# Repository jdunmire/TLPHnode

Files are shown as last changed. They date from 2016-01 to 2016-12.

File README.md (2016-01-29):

TLPHnode
=========
This is a [KiCad](http://kicad-pcb.org/) project for an ESP8266 based
temperature, light, pressure, and humidity node.

Additional information about this node can be found at the 
[Sensor Nodes](http://sensornodeinfo.rockingdlabs.com) website.

Copyright Jerry Dunmire 2016.

This documentation describes Open Hardware and is licensed under the
CERN OHL v. 1.2.

You may redistribute and modify this documentation under the terms of
the CERN OHL v.1.2. (LICENSE.txt). This documentation is distributed
WITHOUT ANY EXPRESS OR IMPLIED WARRANTY, INCLUDING OF MERCHANTABILITY,
SATISFACTORY QUALITY AND FITNESS FOR A PARTICULAR PURPOSE. Please see
the CERN OHL v.1.2 for applicable conditions

Guidelines on how to apply the CERN OHL v1.2 are in the
cern_ohl_v_1_2_howto.pdf file.

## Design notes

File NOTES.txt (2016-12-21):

###Fri 25 Nov 2016 04:06:11 PM PST
    - For a rechargable option:
       - LiFePO4 18350 sized battery
       - bq25070 ($2.46) or ADP5063 ($3.43) charger
       - MIC5528 ($0.19) or AP7365 ($0.40) 3.3v linear regulator
       - Use battery holder with lugs or wires
       - The chargers can yield a battery output voltage 4.9v, or
         possibly higher. So a regulator is needed.
       - Watch for quiesent currents (which are similar to the ESP8266!)

    - The TLPHnode board should be minimized to reduce cost. Use wires
      to the power source which could be 2 Alkaline AA, or a single
      LiFePO4.

    - The charging circuit could be on the PCB but not populated.

    - The linear regulator could be used to provide a USB powered
      option with the AA batteries as backup.

###Sun 27 Nov 2016 11:38:00 AM PST
    - Use a 6 pin connector and ribbon so that the prgm switch can be
      moved to the 'programming' board.
    - Use a LDO linear regulator on the sensor board to protect from
      over voltage of LiFePO4, or even LiPoly, batteries.
    - Put the battery charger IC on the programming board or a separate
      battery supply board.
    - The 'programming' board can be fab as part of the sensor board.
      Use holes or a cutout to make it easier to separate the board.

###Mon 05 Dec 2016 11:53:34 AM PST
    - ST Micro is not forthcoming on the adjustable regulator. So try
      the fixed, even though it is small. Consider laying out a foot
      print for an alternative regulator in addition to the ST Micro.
      I'm not ready to give up on the ST Micro regulator because it has
      such a log quesent current.
      
    TODO:
      - fix alignment between ESP-12 model and ESP-12E footprint - DONE
      - Change pin numbering on ESP-12E footprint to match ESP-12 - DONE
      - change to ESP-12
      - Re-organize footprints - DONE
      - Add 3d models
            - Regulator - flipchip-4
            - RPC connector
            - Switch
            
      - Settle on FPC connector (datasheet is wrong)
      - Update BOM at Digikey
      - 

###Tue 06 Dec 2016 10:00:03 AM PST
    - In order to use a 4 layer board for less than the cost of the last
      board, the area must be less than 1.42 square inches.
    - Keep in mind that a 2 layer board is still 1/2 of that price, but
      the there are other advantages including smaller traces, drills
      and annual rings.

    LIBRARIES
    ---------
    KiCAD has three collections that could be described as libraries:
        - schematic symbols (typically in a library/ directory)
        - 3d models (typically in a modules/packages3d/ directory)
        - footprints
          These are the tough ones to keep straight.
            - The new 'footprint collection structure' is a directory of
              directories.
            - Each sub-directory ends in .pretty.
            - Actual footprints are in individual files beneath the
              *.pretty/ directories.
            - Each *.pretty directory must be added as a separate path.
            - Each *.pretty directory is an individual git repository.
            - There is not clear parent directory name, though in
              ~/kicad/README.md I proposed putting them in the modules/
              directory with the 3d-models

###Thu 08 Dec 2016 09:47:13 PM PST
    - The LPS25HB (pressure sensor) can not be used on an OSH 2 layer
      board because there is not enough clearance between the corner
      pins. The error is 0.3 mils.
    - Set the default design rules as close to the 2 layer as possible,
      while allowing the LPS25HB to be used.

###Mon 12 Dec 2016 02:35:20 PM PST
    - Changed to 6-pin FPC connnector and 2-pin through-hole connector
      for power.

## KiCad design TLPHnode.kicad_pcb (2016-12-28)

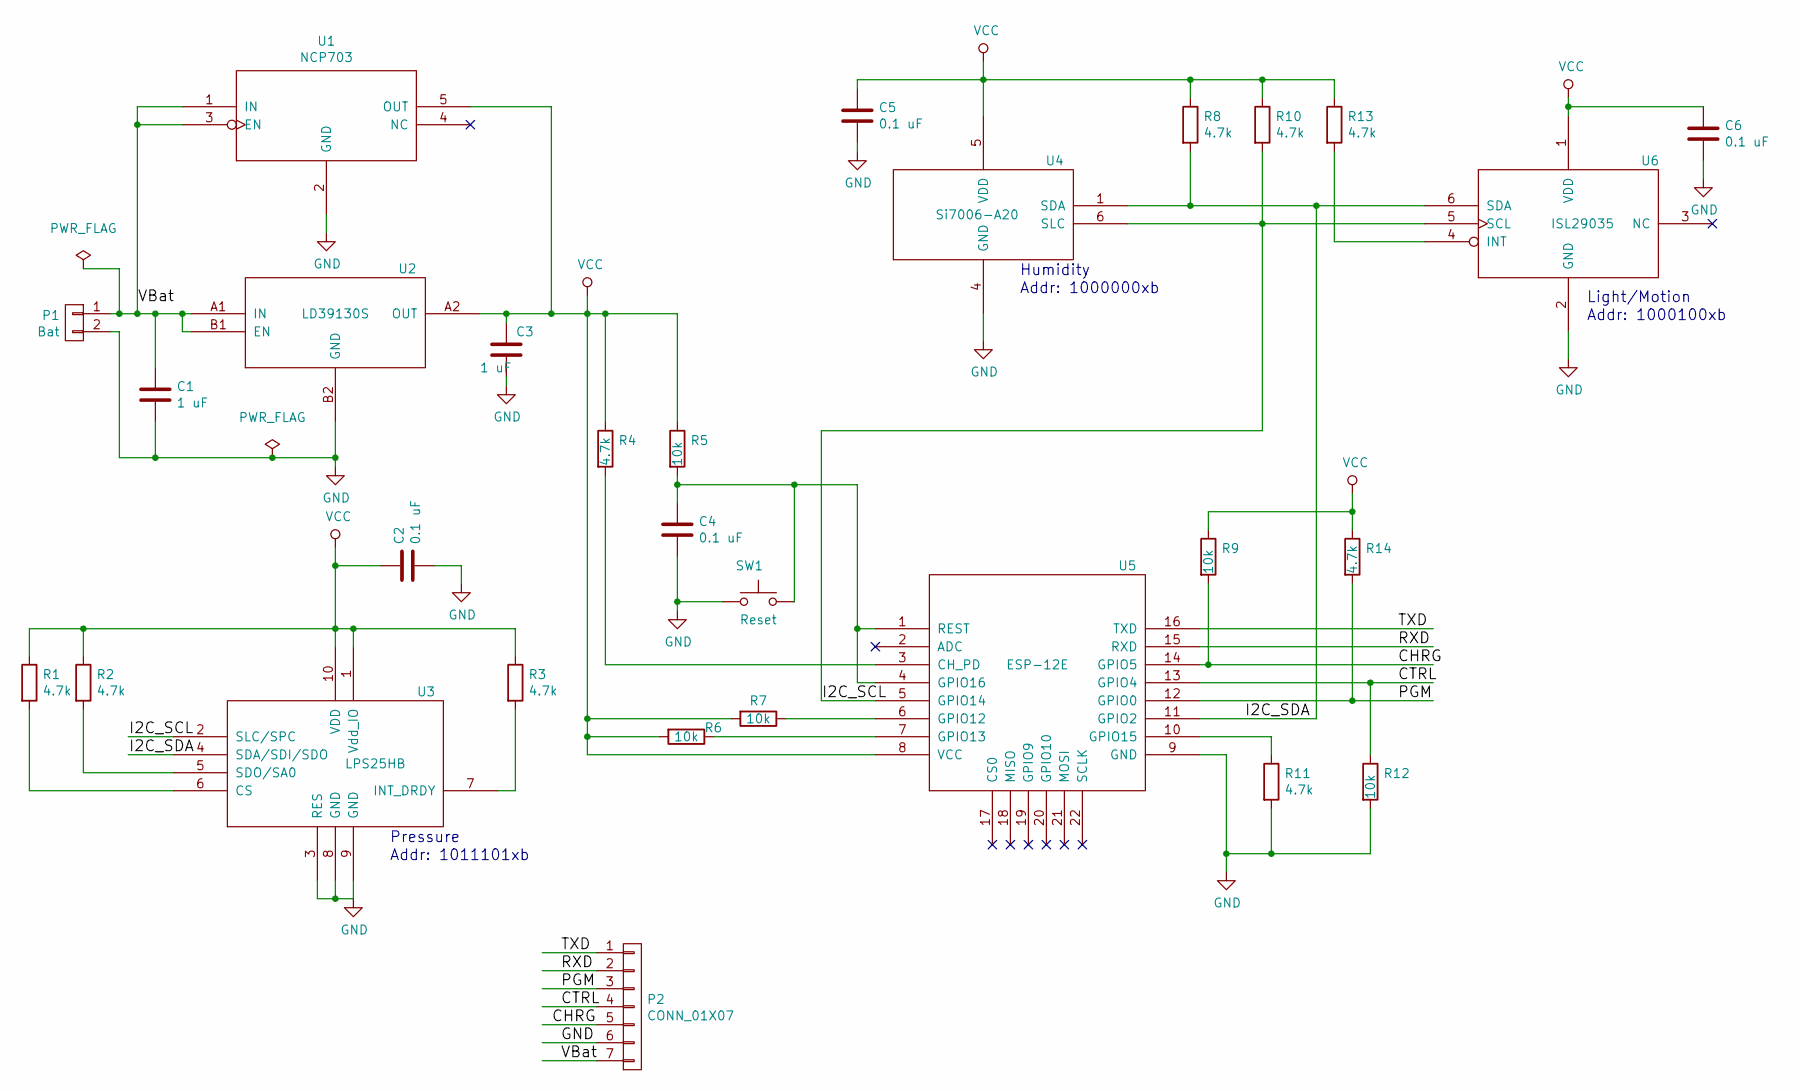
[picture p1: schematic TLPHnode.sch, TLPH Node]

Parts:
C1, C3: 1 uF; C_0603
C2, C4, C5, C6: 0.1 uF; C_0603
P1: Bat; Pin_Header_Straight_1x02
P2: CONN_01X07; FPC_conn-7_8x4.9mm_Pitch0.5mm
R1, R2, R3, R4, R8, R10, R11, R13, R14: 4.7k; R_0603
R5, R6, R7, R9, R12: 10k; R_0603
SW1: Reset; ESwitch-SMD-4
U1: NCP703; NCP703-TSOP-5
U2: LD39130S; LD39130S-FlipChip-4
U3: LPS25HB; LPS25HB-HLGA-10L-2.5x2.5mm
U4: Si7006-A20; Si7006_A20-DFN-6
U5: ESP-12E
U6: ISL29035; ISL29035-DFN-6-1.5x1.6mm_Pitch0.5mm

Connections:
/CHRG: P2.5, R9.2, U5.14 (GPIO5)
/CTRL: P2.4, R12.1, U5.13 (GPIO4)
/I2C_SCL: R10.2, U3.2 (SLC/SPC), U4.6 (SLC), U5.5 (GPIO14), U6.5 (SCL)
/I2C_SDA: R8.2, U3.4 (SDA/SDI/SDO), U4.1 (SDA), U5.11 (GPIO2), U6.6 (SDA)
/PGM: P2.3, R14.2, U5.12 (GPIO0)
/RXD: P2.2, U5.15 (RXD)
/TXD: P2.1, U5.16 (TXD)
/VBat: C1.1, P1.1, P2.7, U1.1 (IN), U1.3 (EN), U2.A1 (IN), U2.B1 (EN)
GND: C1.2, C2.2, C3.2, C4.2, C5.2, C6.2, P1.2, P2.6, R11.2, R12.2, SW1.1, U1.2 (GND), U2.B2 (GND), U3.3 (RES), U3.8 (GND), U3.9 (GND), U4.4 (GND), U5.9 (GND), U6.2 (GND)
unnamed: C4.1, R5.2, SW1.2, U5.1 (REST), U5.4 (GPIO16)
unnamed: R1.2, U3.6 (CS)
unnamed: R2.2, U3.5 (SDO/SA0)
unnamed: R3.2, U3.7 (INT_DRDY)
unnamed: R4.2, U5.3 (CH_PD)
unnamed: R6.1, U5.7 (GPIO13)
unnamed: R7.1, U5.6 (GPIO12)
unnamed: R11.1, U5.10 (GPIO15)
unnamed: R13.2, U6.4 (INT)
VCC: C2.1, C3.1, C5.1, C6.1, R1.1, R2.1, R3.1, R4.1, R5.1, R6.2, R7.2, R8.1, R9.1, R10.1, R13.1, R14.1, U1.5 (OUT), U2.A2 (OUT), U3.1 (Vdd_IO), U3.10 (VDD), U4.5 (VDD), U5.8 (VCC), U6.1 (VDD)

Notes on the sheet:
Pressure
Light/Motion
Humidity
Addr: 1011101xb
Addr: 1000000xb
Addr: 1000100xb

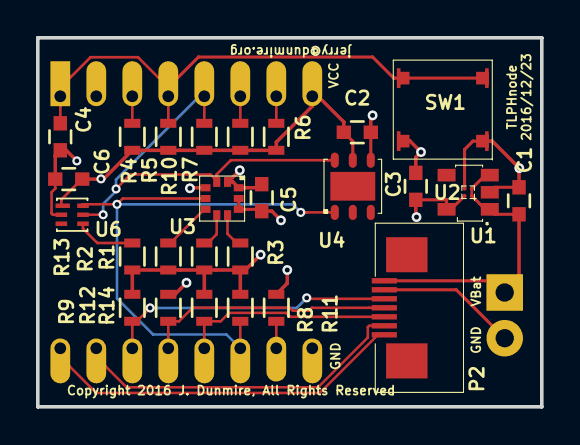
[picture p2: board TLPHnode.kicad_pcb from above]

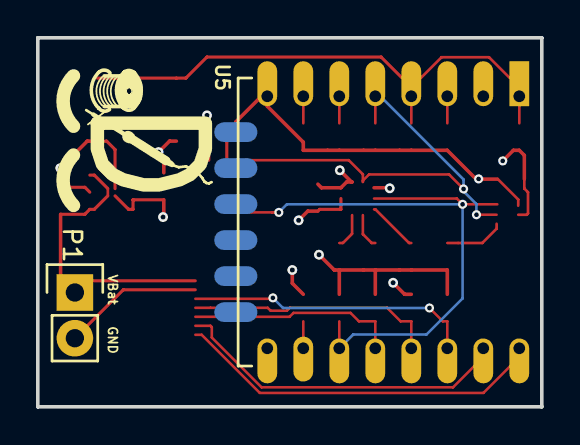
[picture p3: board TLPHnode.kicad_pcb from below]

Board: 4 copper layers, 28.0 x 20.5 mm, 30 parts (3 on the bottom side), 19 nets.

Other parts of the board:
Ref**: RockingDLogo_9x7

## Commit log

2016-01-29 Add my title block and frame
    On branch master
    new file: rockingdlabs_letter_with_logo.kicad_wks
2016-01-29 Add initial KiCad project files
    Files created by 'New Project'
    [TLPHnode.kicad_pcb, TLPHnode.sch]
2016-01-29 Added title block
    new file: TLPHnode-cache.lib
    modified: TLPHnode.pro
    modified: TLPHnode.sch
    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
    [TLPHnode.sch]
2016-02-02 Add datasheet for jumper cable
    modified: datasheets/getdatasheets.sh
    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
2016-11-27 Add linear regulators and battery chargers
    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
2016-12-06 Check-point: ESP-12E with two voltage regulators
    Initial attempts at a layout show that I should use the ESP-12 footprint
    to avoid pads for the extra connections on the end of the ESP-12E.
    modified: TLPHnode-cache.lib
    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
    [TLPHnode.sch]
2016-12-06 Add datasheet for battery connector.
    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
2016-12-06 Use JST PH footprint for battery
    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
    [TLPHnode.sch]
2016-12-06 Ignore datasheets with upper case suffixes
    modified: datasheets/.gitignore
2016-12-06 Checkpoint before moving to kicad-rockingdlabs library
    [TLPHnode.sch]
2016-12-07 Adjust paths for unified rockingdlabs library
    modified: TLPHnode.kicad_pcb
    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
    [TLPHnode.kicad_pcb, TLPHnode.sch]
2016-12-07 Clarify labels
    Id->Sheet
    Sheet->Path
    modified: rockingdlabs_letter_with_logo.kicad_wks
    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
2016-12-09 Add 5pin connector
2016-12-09 Check-point
    - some parts tentatively placed
    - commiting before adding any traces
    - design rules set. OSH 4-layer
    new file: TLPHnode.net
    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
    [TLPHnode.kicad_pcb, TLPHnode.sch]
2016-12-09 Check-point: First placement
    [TLPHnode.kicad_pcb]
2016-12-09 Check-point: 28x20.5mm board
    - Only ESP-12E and power connector on the back
    [TLPHnode.kicad_pcb]
2016-12-10 Fix connection
    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
    [TLPHnode.sch]
2016-12-10 Check-point: layout passes DRM, References visible
    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
    [TLPHnode.kicad_pcb]
2016-12-10 Add copyright notice, partname and date
    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
    [TLPHnode.kicad_pcb]
2016-12-10 Add Logo
    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
    [TLPHnode.kicad_pcb]
2016-12-12 Change Bat to a through-hole connector
    - Add VBat to P2 so that a single connector can
    be used when connecting to a charger/breakout/debug board
    - Use a two-pin through-hole header for VBat to make it
    easy to solder wires rather than use a connector.
    On branch AltPower
    modified: TLPHnode.net
    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
    [TLPHnode.kicad_pcb, TLPHnode.sch]
2016-12-15 Change battery connection to bare pads
    - Use pin model rather than socket
    - remove 3d model
    [TLPHnode.kicad_pcb, TLPHnode.sch]
2016-12-21 Set grid and drill origin point
    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
    [TLPHnode.kicad_pcb]
2016-12-24 Add Charger control signals to P2
    - All routes removed.
    On branch addChrgCtrl
    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
    [TLPHnode.kicad_pcb, TLPHnode.sch]
2016-12-28 Checkpoint - Routing complete, 7-pin P2
    - Includes control and monitoring signals for battery charger
    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
    [TLPHnode.kicad_pcb, TLPHnode.sch]

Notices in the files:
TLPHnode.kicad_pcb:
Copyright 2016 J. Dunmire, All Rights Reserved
